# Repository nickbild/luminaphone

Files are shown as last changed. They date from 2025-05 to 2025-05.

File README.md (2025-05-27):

# Luminaphone

The Luminaphone was an odd electronic musical instrument created 100 years ago. Only one prototype was ever built, and no recordings of its music have survived. I have reconstructed this unusual instrument to see what it sounded like.

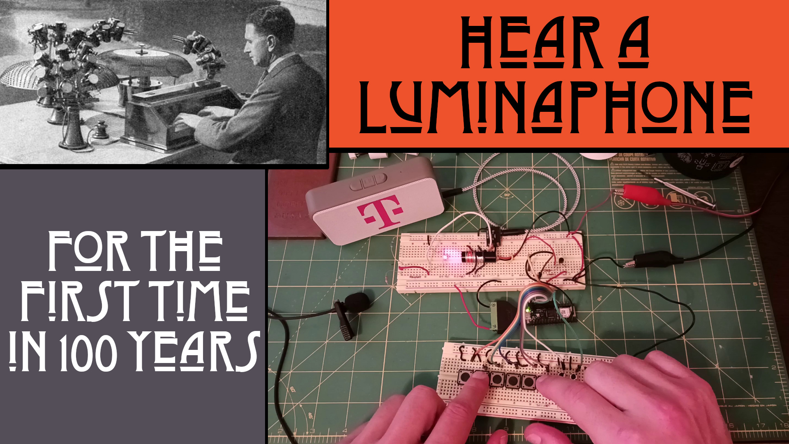
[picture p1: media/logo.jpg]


**Check out the video on YouTube:**
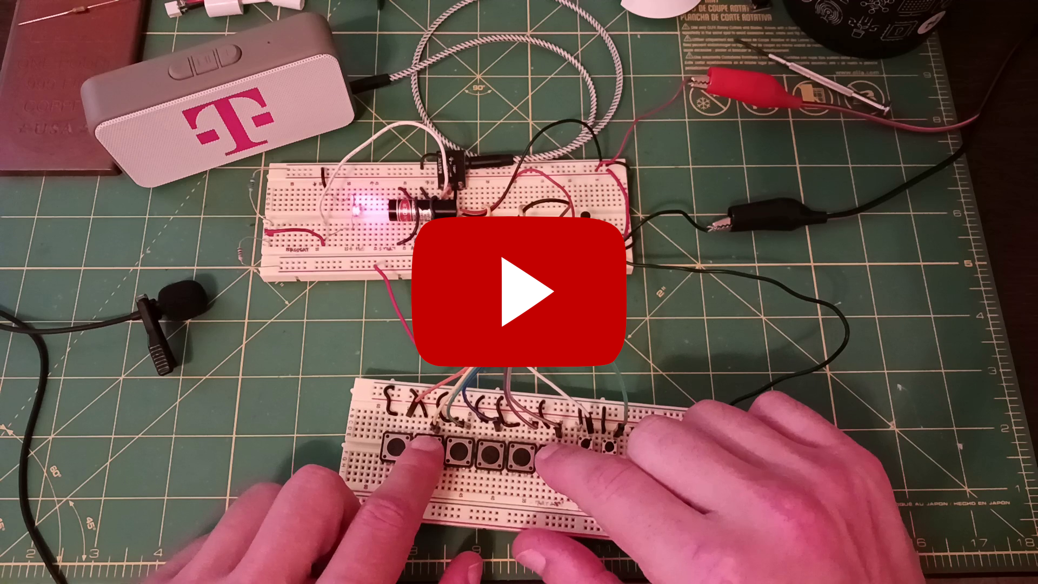
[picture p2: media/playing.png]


## Background

The Luminaphone has a really interesting history. It was invented by a man named Harry Grindell Matthews. 

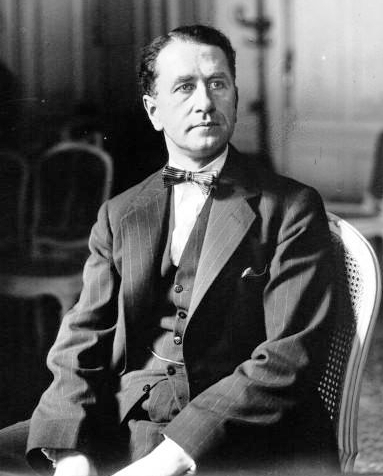
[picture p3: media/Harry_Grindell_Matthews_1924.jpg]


He invented a lot of other things as well, like a wireless remote control system for submarines and a self-righting flying machine, but he is best known for a dubious claim he made about creating what he called a Death Ray. It was supposed to instantly and silently kill, and bring motors to a halt. He claimed it would end wars forever. 

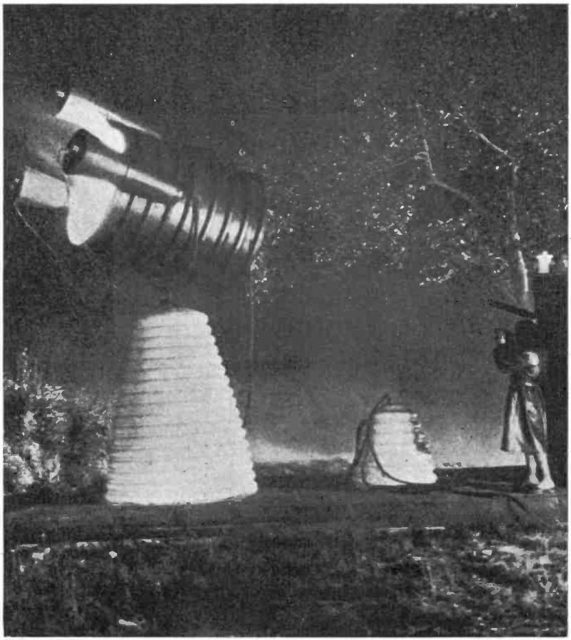
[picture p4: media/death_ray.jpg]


All of this created quite the international stir, but he was never able to back up those claims with a demonstration, and so he lost the people’s trust. A NYT article from the time about the Luminaphone derisively called him Death Ray Man.

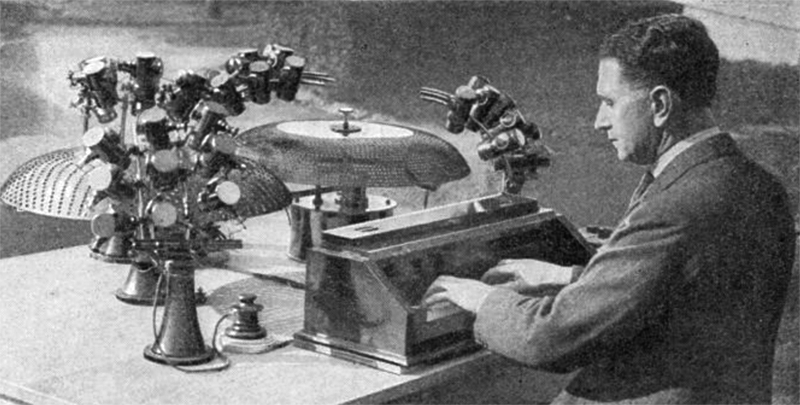
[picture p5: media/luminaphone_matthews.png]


The Luminaphone, on the other hand, was definitely real. People who heard it described it as sounding something like a little pipe organ.

## How It Works

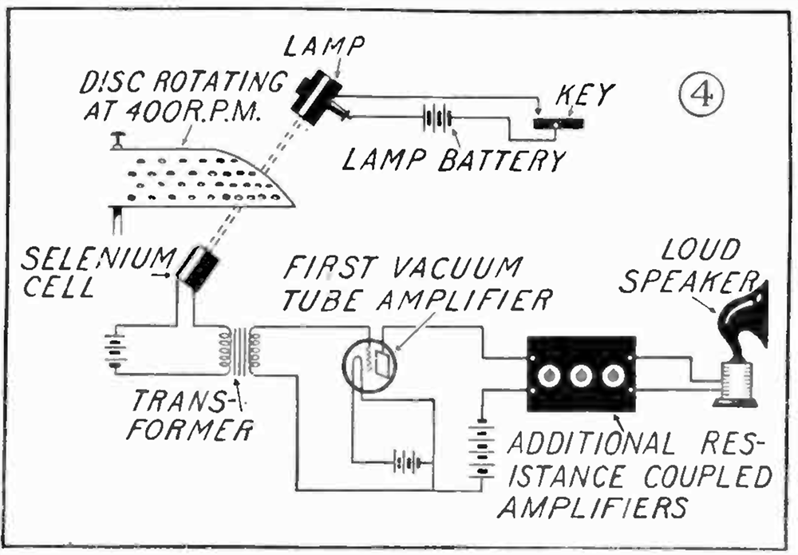
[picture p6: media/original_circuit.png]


This is what Matthews’ Luminaphone circuit looked like. Each key turned on an incandescent bulb that was directed at a particular ring in a metal disc, which was spinning at 400 RPMs. Each ring had a pattern of holes made in it. Light that made it through the holes in the disc fell on a selenium cell (an early photoresistor), which altered the amount of current that flowed through it, and the transformer it was in series with. This transformer removed any DC components from the signal, leaving just the light modulated signal on the other side of the transformer. This was fed into some amplifiers before it reached a speaker.

The reason the spinning disc was necessary was due to the technological limitations of the day. Incandescent bulbs do not turn on and off rapidly as a modern LED or laser does, for example, so the holes in the metal provided the fast transitions. This setup also provided the control — it specified *when* the light should turn off. But in today’s world, there are much better ways to achieve these goals.

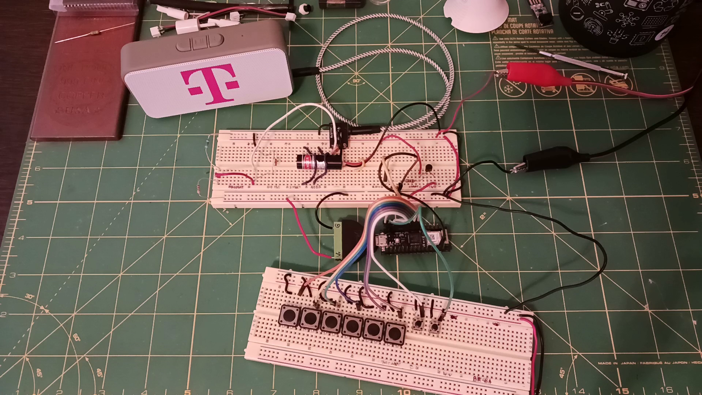
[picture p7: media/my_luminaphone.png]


For this reason, I did things differently, but achieved the same result. I did away with the spinning disk and instead replaced it with a laser that can turn on and off very rapidly. I paired that with an Arduino microcontroller development board (Nano 33 IoT) that gives me precise control over exactly when the laser is turned on or off.

GPIO pins are rapidly switched on and off in a pattern I define when buttons are pressed. That switches a transistor that controls the current flowing through the laser. The laser shines on a photoresistor, which turns the light into an electrical signal that is played through a speaker.

Now for those patterns. Each musical note has a particular frequency. For example, middle C has a frequency of about 261 hertz, and D4 is 293 hertz. I tailored the on-off patterns to match these frequencies.

Here is a schematic of my circuit:
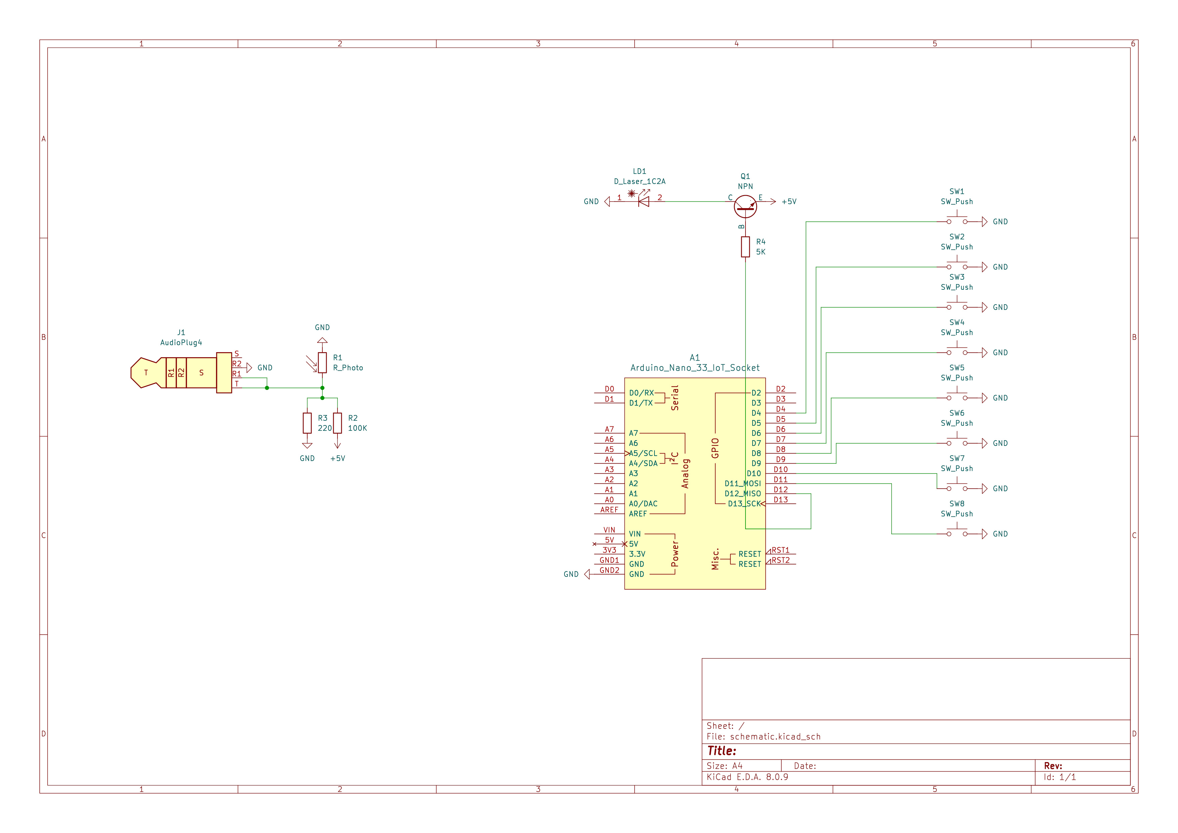
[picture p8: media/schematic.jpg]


## Bill of Materials

- 1 x Arduino Nano 33 IoT
- 1 x 2N3904 NPN transistor
- 1 x Laser Diode — 5mW 650nm Red
- 1 x TRRS breakout board
- 1 x Speaker
- 1 x Photoresistor
- 1 x 100K resistor
- 1 x 5K resistor
- 1 x 220 resistor
- 8 x Pushbuttons

## About the Author

[Nick A. Bild, MS](https://nickbild79.firebaseapp.com/#!/)

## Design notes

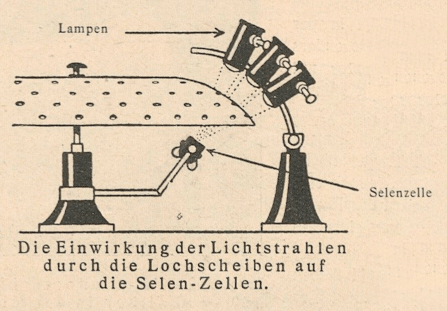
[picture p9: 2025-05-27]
media/luminaphone_close.png

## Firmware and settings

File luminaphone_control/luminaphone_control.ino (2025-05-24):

String note = "";
int c;

void setup() {
  pinMode(4, INPUT_PULLUP);
  pinMode(5, INPUT_PULLUP);
  pinMode(6, INPUT_PULLUP);
  pinMode(7, INPUT_PULLUP);
  pinMode(8, INPUT_PULLUP);
  pinMode(9, INPUT_PULLUP);
  pinMode(10, INPUT_PULLUP);
  pinMode(11, INPUT_PULLUP);

  pinMode(12, OUTPUT);
}

void loop() {
  if (digitalRead(4) == LOW) { // E3
    note = "111111111111111111111111111111111111111111111111111111111111111111111111111111111111111111111111111111111111111111111111111111111111111111111111111111111111111111111111111111111111111111111111111111111111111111111111111111111111111111111111111111111111111111111111111111111111111111111111111111111111111111111111111111111111111111111111111111111111111111111111111111111111111111111111111111111111111111111111111111111111111111111111111111111111111111111111111111111111111111111111111111111111111111111111111111111111111111111111111111111111111111111111111111111111111111111111111111111111111111111111111111111111111111111111111111111111111111111111111111111111111111111111111111111111111111111111111111111111111111111111111111111111111111111111111111111111111111111111111111111111111111111111111111111111111111111111111111111111111111111111111111111111111111111111111111111111111111111111111111111111111111111111111111111111111111111111111111111111111111111111111111111111111111111111111111111111111111111111111111111111111111111111111111111111111111111111111111111111111111111111111111111111111111111111111111111111111111111111111111111111111111111111111111111111111000000000000000000000000000000000000000000000000000000000000000000000000000000000000000000000000000000000000000000000000000000000000000000000000000000000000000000000000000000000000000000000000000000000000000000000000000000000000000000000000000000000000000000000000000000000000000000000000000000000000000000000000000000000000000000000000000000000000000000000000000000000000000000000000000000000000000000000000000000000000000000000000000000000000000000000000000000000000000000000000000000000000000000000000000000000000000000000000000000000000000000000000000000000000000000000000000000000000000000000000000000000000000000000000000000000000000000000000000000000000000000000000000000000000000000000000000000000000000000000000000000000000000000000000000000000000000000000000000000000000000000000000000000000000000000000000000000000000000000000000000000000000000000000000000000000000000000000000000000000000000000000000000000000000000000000000000000000000000000000000000000000000000000000000000000000000000000000000000000000000000000000000000000000000000000000000000000000000000000000000000000000000000000000000000000000000000000000000000000000000000000000000000000000000000";
  } else if (digitalRead(5) == LOW) { //G3
    note = "11111111111111111111111111111111111111111111111111111111111111111111111111111111111111111111111111111111111111111111111111111111111111111111111111111111111111111111111111111111111111111111111111111111111111111111111111111111111111111111111111111111111111111111111111111111111111111111111111111111111111111111111111111111111111111111111111111111111111111111111111111111111111111111111111111111111111111111111111111111111111111111111111111111111111111111111111111111111111111111111111111111111111111111111111111111111111111111111111111111111111111111111111111111111111111111111111111111111111111111111111111111111111111111111111111111111111111111111111111111111111111111111111111111111111111111111111111111111111111111111111111111111111111111111111111111111111111111111111111111111111111111111111111111111111111111111111111111111111111111111111111111111111111111111111111111111111111111111111111111111111111111111111111111111111111111111111111111111111111111111111111110000000000000000000000000000000000000000000000000000000000000000000000000000000000000000000000000000000000000000000000000000000000000000000000000000000000000000000000000000000000000000000000000000000000000000000000000000000000000000000000000000000000000000000000000000000000000000000000000000000000000000000000000000000000000000000000000000000000000000000000000000000000000000000000000000000000000000000000000000000000000000000000000000000000000000000000000000000000000000000000000000000000000000000000000000000000000000000000000000000000000000000000000000000000000000000000000000000000000000000000000000000000000000000000000000000000000000000000000000000000000000000000000000000000000000000000000000000000000000000000000000000000000000000000000000000000000000000000000000000000000000000000000000000000000000000000000000000000000000000000000000000000000000000000000000000000000000000000000000000000000000000000000000000000000000000000000000000000000000000000000000000";
  } else if (digitalRead(6) == LOW) { // A3
    note = "111111111111111111111111111111111111111111111111111111111111111111111111111111111111111111111111111111111111111111111111111111111111111111111111111111111111111111111111111111111111111111111111111111111111111111111111111111111111111111111111111111111111111111111111111111111111111111111111111111111111111111111111111111111111111111111111111111111111111111111111111111111111111111111111111111111111111111111111111111111111111111111111111111111111111111111111111111111111111111111111111111111111111111111111111111111111111111111111111111111111111111111111111111111111111111111111111111111111111111111111111111111111111111111111111111111111111111111111111111111111111111111111111111111111111111111111111111111111111111111111111111111111111111111111111111111111111111111111111111111111111111111111111111111111111111111111111111111111111111111111111111111111111111111000000000000000000000000000000000000000000000000000000000000000000000000000000000000000000000000000000000000000000000000000000000000000000000000000000000000000000000000000000000000000000000000000000000000000000000000000000000000000000000000000000000000000000000000000000000000000000000000000000000000000000000000000000000000000000000000000000000000000000000000000000000000000000000000000000000000000000000000000000000000000000000000000000000000000000000000000000000000000000000000000000000000000000000000000000000000000000000000000000000000000000000000000000000000000000000000000000000000000000000000000000000000000000000000000000000000000000000000000000000000000000000000000000000000000000000000000000000000000000000000000000000000000000000000000000000000000000000000000000000000000000000000000000000000000000000000000000000000000000000000000000000000000000000";
  } else if (digitalRead(7) == LOW) { // A3/B3
    note = "11111111111111111111111111111111111111111111111111111111111111111111111111111111111111111111111111111111111111111111111111111111111111111111111111111111111111111111111111111111111111111111111111111111111111111111111111111111111111111111111111111111111111111111111111111111111111111111111111111111111111111111111111111111111111111111111111111111111111111111111111111111111111111111111111111111111111111111111111111111111111111111111111111111111111111111111111111111111111111111111111111111111111111111111111111111111111111111111111111111111111111111111111111111111111111111111111111111111111111111111111111111111111111111111111111111111111111111111111111111111111111111111111111111111111111111111111111111111111111111111111111111111111111111111111111111111111111111111111111111111111111111111111111111111111111111111111110000000000000000000000000000000000000000000000000000000000000000000000000000000000000000000000000000000000000000000000000000000000000000000000000000000000000000000000000000000000000000000000000000000000000000000000000000000000000000000000000000000000000000000000000000000000000000000000000000000000000000000000000000000000000000000000000000000000000000000000000000000000000000000000000000000000000000000000000000000000000000000000000000000000000000000000000000000000000000000000000000000000000000000000000000000000000000000000000000000000000000000000000000000000000000000000000000000000000000000000000000000000000000000000000000000000000000000000000000000000000000000000000000000000000000000000000000000000000000000000000000000000000000000000000000000000000000000000000000000000000000000000000000000000000000000000000000";
  } else if (digitalRead(8) == LOW) { // B3
    note = "11111111111111111111111111111111111111111111111111111111111111111111111111111111111111111111111111111111111111111111111111111111111111111111111111111111111111111111111111111111111111111111111111111111111111111111111111111111111111111111111111111111111111111111111111111111111111111111111111111111111111111111111111111111111111111111111111111111111111111111111111111111111111111111111111111111111111111111111111111111111111111111111111111111111111111111111111111111111111111111111111111111111111111111111111111111111111111111111111111111111111111111111111111111111111111111111111111111111111111111111111111111111111111111111111111111111111111111111111111111111111111111111111111111111111111111111111111111111111111111111111111111111111111111111111111111111111111111111111100000000000000000000000000000000000000000000000000000000000000000000000000000000000000000000000000000000000000000000000000000000000000000000000000000000000000000000000000000000000000000000000000000000000000000000000000000000000000000000000000000000000000000000000000000000000000000000000000000000000000000000000000000000000000000000000000000000000000000000000000000000000000000000000000000000000000000000000000000000000000000000000000000000000000000000000000000000000000000000000000000000000000000000000000000000000000000000000000000000000000000000000000000000000000000000000000000000000000000000000000000000000000000000000000000000000000000000000000000000000000000000000000000000000000000000000000000000000000000000000000000000000000000000000000000000000000000000000000";
  } else if (digitalRead(9) == LOW) { // C4
    note = "11111111111111111111111111111111111111111111111111111111111111111111111111111111111111111111111111111111111111111111111111111111111111111111111111111111111111111111111111111111111111111111111111111111111111111111111111111111111111111111111111111111111111111111111111111111111111111111111111111111111111111111111111111111111111111111111111111111111111111111111111111111111111111111111111111111111111111111111111111111111111111111111111111111111111111111111111111111111111111111111111111111111111111111111111111111111111111111111111111111111111111111111111111111111111111111111111111111111111111111111111111111111111111111111111111111111111111111111111111111111111111111111111111111111111111111111111111111111111111111111111111111110000000000000000000000000000000000000000000000000000000000000000000000000000000000000000000000000000000000000000000000000000000000000000000000000000000000000000000000000000000000000000000000000000000000000000000000000000000000000000000000000000000000000000000000000000000000000000000000000000000000000000000000000000000000000000000000000000000000000000000000000000000000000000000000000000000000000000000000000000000000000000000000000000000000000000000000000000000000000000000000000000000000000000000000000000000000000000000000000000000000000000000000000000000000000000000000000000000000000000000000000000000000000000000000000000000000000000000000000000000000000000000000000000000000000000000000000000000000000000000000000000000000";
  } else if (digitalRead(10) == LOW) { // E4
    note = "11111111111111111111111111111111111111111111111111111111111111111111111111111111111111111111111111111111111111111111111111111111111111111111111111111111111111111111111111111111111111111111111111111111111111111111111111111111111111111111111111111111111111111111111111111111111111111111111111111111111111111111111111111111111111111111111111111111111111111111111111111111111111111111111111111111111111111111111111111111111111111111111111111111111111111111111111111111111111111111111111111111111111111111111111111111111111111111111111111111111111111111111111111111111111111111111111110000000000000000000000000000000000000000000000000000000000000000000000000000000000000000000000000000000000000000000000000000000000000000000000000000000000000000000000000000000000000000000000000000000000000000000000000000000000000000000000000000000000000000000000000000000000000000000000000000000000000000000000000000000000000000000000000000000000000000000000000000000000000000000000000000000000000000000000000000000000000000000000000000000000000000000000000000000000000000000000000000000000000000000000000000000000000000000000000000000000000000000000000000000000000000000000000000";
  } else if (digitalRead(11) == LOW) { // G4
    note = "11111111111111111111111111111111111111111111111111111111111111111111111111111111111111111111111111111111111111111111111111111111111111111111111111111111111111111111111111111111111111111111111111111111111111111111111111111111111111111111111111111111111111111111111111111111111111111111111111111111111111111111111111111111111111111111111111111111111111111111111111111111111111111111111111111111111111111111111111111111111111111111111111111111111111111111111111111111111111111111111111111111110000000000000000000000000000000000000000000000000000000000000000000000000000000000000000000000000000000000000000000000000000000000000000000000000000000000000000000000000000000000000000000000000000000000000000000000000000000000000000000000000000000000000000000000000000000000000000000000000000000000000000000000000000000000000000000000000000000000000000000000000000000000000000000000000000000000000000000000000000000000000000000000000000000000000000000000000000000000000000000000000000000000";
  } else {
    note = "";
  }

  c = note.length();
  for (int x=0; x<c; x++) {
    if (note[x] == '1') {
      digitalWrite(12, HIGH);
    } else if (note[x] == '0') {
      digitalWrite(12, LOW);
    }
  }

}

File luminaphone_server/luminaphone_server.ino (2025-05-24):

#include <SPI.h>
#include <WiFiNINA.h>

#include "arduino_secrets.h" 
char ssid[] = SECRET_SSID;
char pass[] = SECRET_PASS;
int keyIndex = 0;

int first_delay = 0;
int second_delay = 0;
String note_vals = "";

int status = WL_IDLE_STATUS;
WiFiServer server(80);

void setup() {
  Serial.begin(9600);      // initialize serial communication
  pinMode(12, OUTPUT);      // set the LED pin mode

  // check for the WiFi module:
  if (WiFi.status() == WL_NO_MODULE) {
    Serial.println("Communication with WiFi module failed!");
    while (true);
  }

  String fv = WiFi.firmwareVersion();
  if (fv < WIFI_FIRMWARE_LATEST_VERSION) {
    Serial.println("Please upgrade the firmware");
  }

  // Attempt to connect to WiFi network.
  while (status != WL_CONNECTED) {
    Serial.print("Attempting to connect to Network named: ");
    Serial.println(ssid);

    // Connect to WPA/WPA2 network. Change this line if using open or WEP network:
    status = WiFi.begin(ssid, pass);
    // wait 10 seconds for connection:
    delay(10000);
  }
  server.begin();                           // start the web server on port 80
  printWifiStatus();                        // you're connected now, so print out the status
}


void loop() {
  String lastLine = "";
  WiFiClient client = server.available();   // listen for incoming clients

  if (client) {                             // if you get a client,
    Serial.println("new client");           // print a message out the serial port
    String currentLine = "";                // make a String to hold incoming data from the client
    while (client.connected()) {            // loop while the client's connected
      if (client.available()) {             // if there's bytes to read from the client,
        char c = client.read();             // read a byte, then
        Serial.write(c);                    // print it out to the serial monitor
        if (c == '\n') {                    // if the byte is a newline character

          // if the current line is blank, you got two newline characters in a row.
          // that's the end of the client HTTP request, so send a response:
          if (currentLine.length() == 0) {
            // HTTP headers always start with a response code (e.g. HTTP/1.1 200 OK)
            // and a content-type so the client knows what's coming, then a blank line:
            client.println("HTTP/1.1 200 OK");
            client.println("Content-type:text/html");
            client.println();

            // the content of the HTTP response follows the header:
            client.print("Click <a href=\"/H\">here</a> turn the LED on pin 9 on<br>");
            client.print("Click <a href=\"/L\">here</a> turn the LED on pin 9 off<br>");

            // The HTTP response ends with another blank line:
            client.println();
            // break out of the while loop:
            break;
          } else {    // if you got a newline, then clear currentLine:
            lastLine = currentLine;
            currentLine = "";
          }
        } else if (c != '\r') {  // if you got anything else but a carriage return character,
          currentLine += c;      // add it to the end of the currentLine
        }


        if (currentLine.endsWith("SETFIRST")) {
          int start = currentLine.indexOf("GET /") + 5;
          int end = currentLine.indexOf("SETFIRST HTTP/1.1");
          String val = currentLine.substring(start, end);
          first_delay = val.toInt();
          note_vals = "";
        }
        if (currentLine.endsWith("SETSECOND")) {
          int start = currentLine.indexOf("GET /") + 5;
          int end = currentLine.indexOf("SETSECOND HTTP/1.1");
          String val = currentLine.substring(start, end);
          second_delay = val.toInt();
          note_vals = "";
        }
        if (currentLine.endsWith("NOTEVALS")) {
          int start = currentLine.indexOf("GET /") + 5;
          int end = currentLine.indexOf("NOTEVALS");
          note_vals = currentLine.substring(start, end);
        }

      }
    }
    

    // close the connection:
    client.stop();
    Serial.println("client disconnected");
  }


  if (note_vals.length() > 0) {
    int c = note_vals.length();

    for (int i=0; i<500; i++) {
      for (int x=0; x<c; x++) {
        if (note_vals[x] == '1') {
          digitalWrite(12, HIGH);
        } else if (note_vals[x] == '0') {
          digitalWrite(12, LOW);
        }
      }
    }
    
    note_vals = "";

  } else if (first_delay == 0 && second_delay == 0) {
    digitalWrite(12, LOW);

  } else {
    for(int i=0; i<400; i++) {
      digitalWrite(12, HIGH);
      delayMicroseconds(first_delay);

      digitalWrite(12, LOW);
      delayMicroseconds(second_delay);
    }
  }


}

void printWifiStatus() {
  // print the SSID of the network you're attached to:
  Serial.print("SSID: ");
  Serial.println(WiFi.SSID());

  // print your board's IP address:
  IPAddress ip = WiFi.localIP();
  Serial.print("IP Address: ");
  Serial.println(ip);

  // print the received signal strength:
  long rssi = WiFi.RSSI();
  Serial.print("signal strength (RSSI):");
  Serial.print(rssi);
  Serial.println(" dBm");
  // print where to go in a browser:
  Serial.print("To see this page in action, open a browser to http://");
  Serial.println(ip);
}
